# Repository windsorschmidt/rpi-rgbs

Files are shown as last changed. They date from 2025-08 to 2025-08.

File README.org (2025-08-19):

#+OPTIONS: toc:nil

* About

TV-compatible RGBS video output board for Raspberry Pi.

[[rpi-rgbs.png?raw=true]]

* Features

- 6-bit R-2R video DAC with buffered 75Ω output on VGA (DE-15) connector
- Composite video sync generator using XNOR logic gates
- Low-pass reconstruction filter audio DAC output on 3.5" phono jack

* Status

Revision 3 tested working with a Raspberry Pi 4.

* License

Circuit schematic and PCB layout are licensed under CERN-OHL-S v2.

See [[LICENSE.txt]].

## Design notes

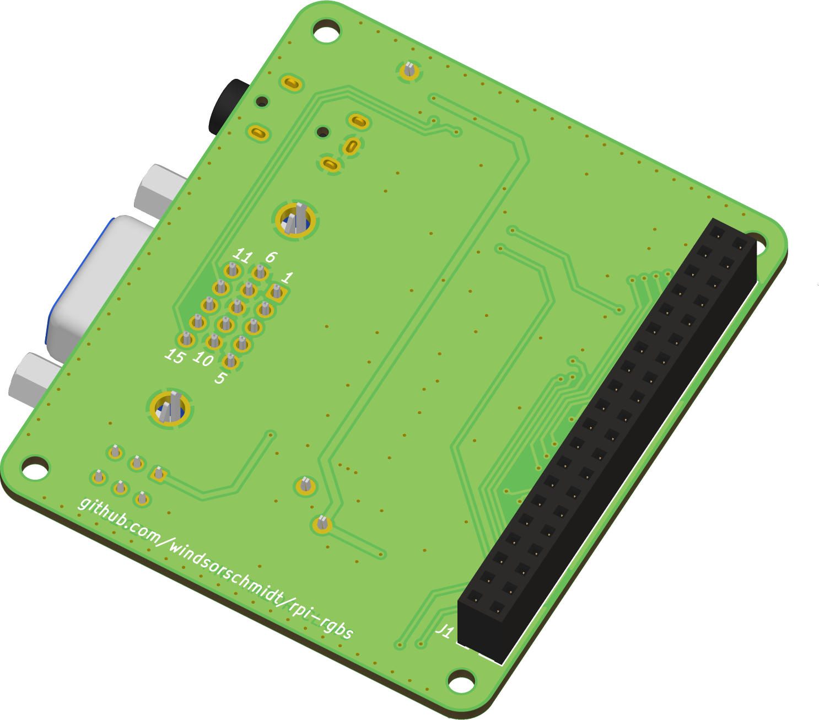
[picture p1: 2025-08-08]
render_bottom.png

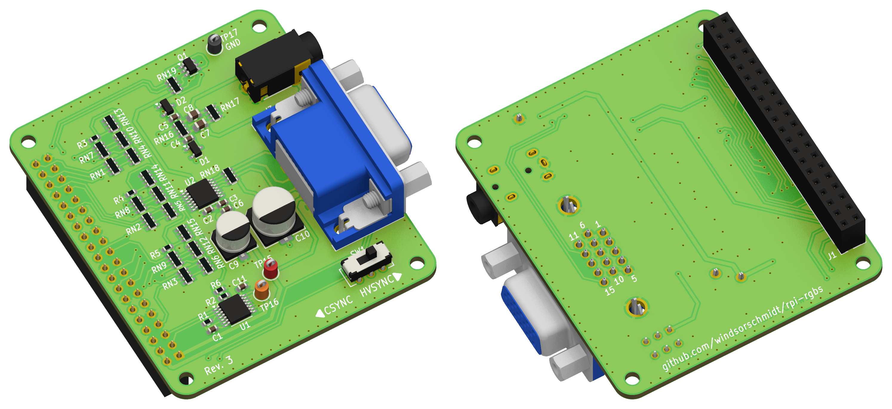
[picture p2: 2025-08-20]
rpi-rgbs.png

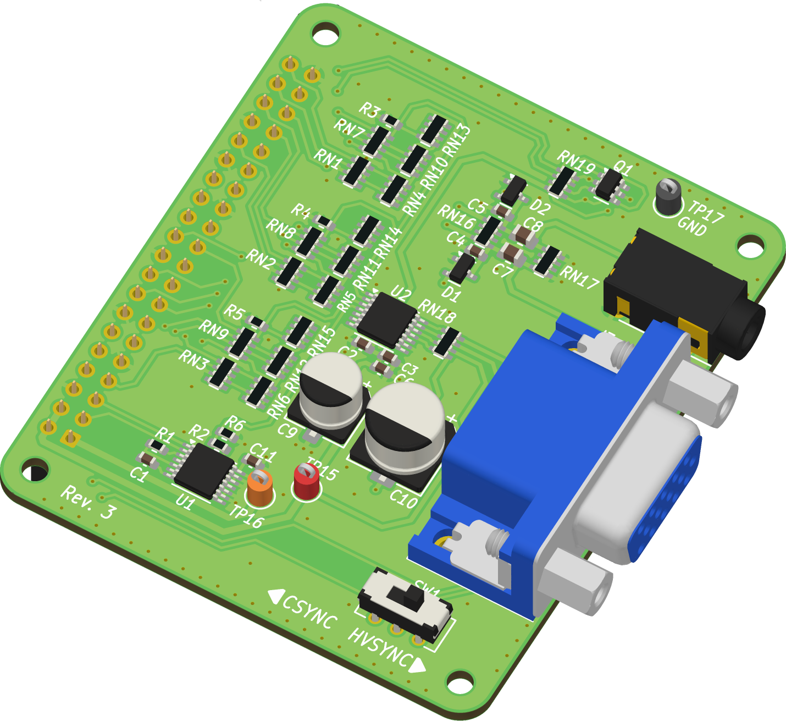
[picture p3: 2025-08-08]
render_top.png

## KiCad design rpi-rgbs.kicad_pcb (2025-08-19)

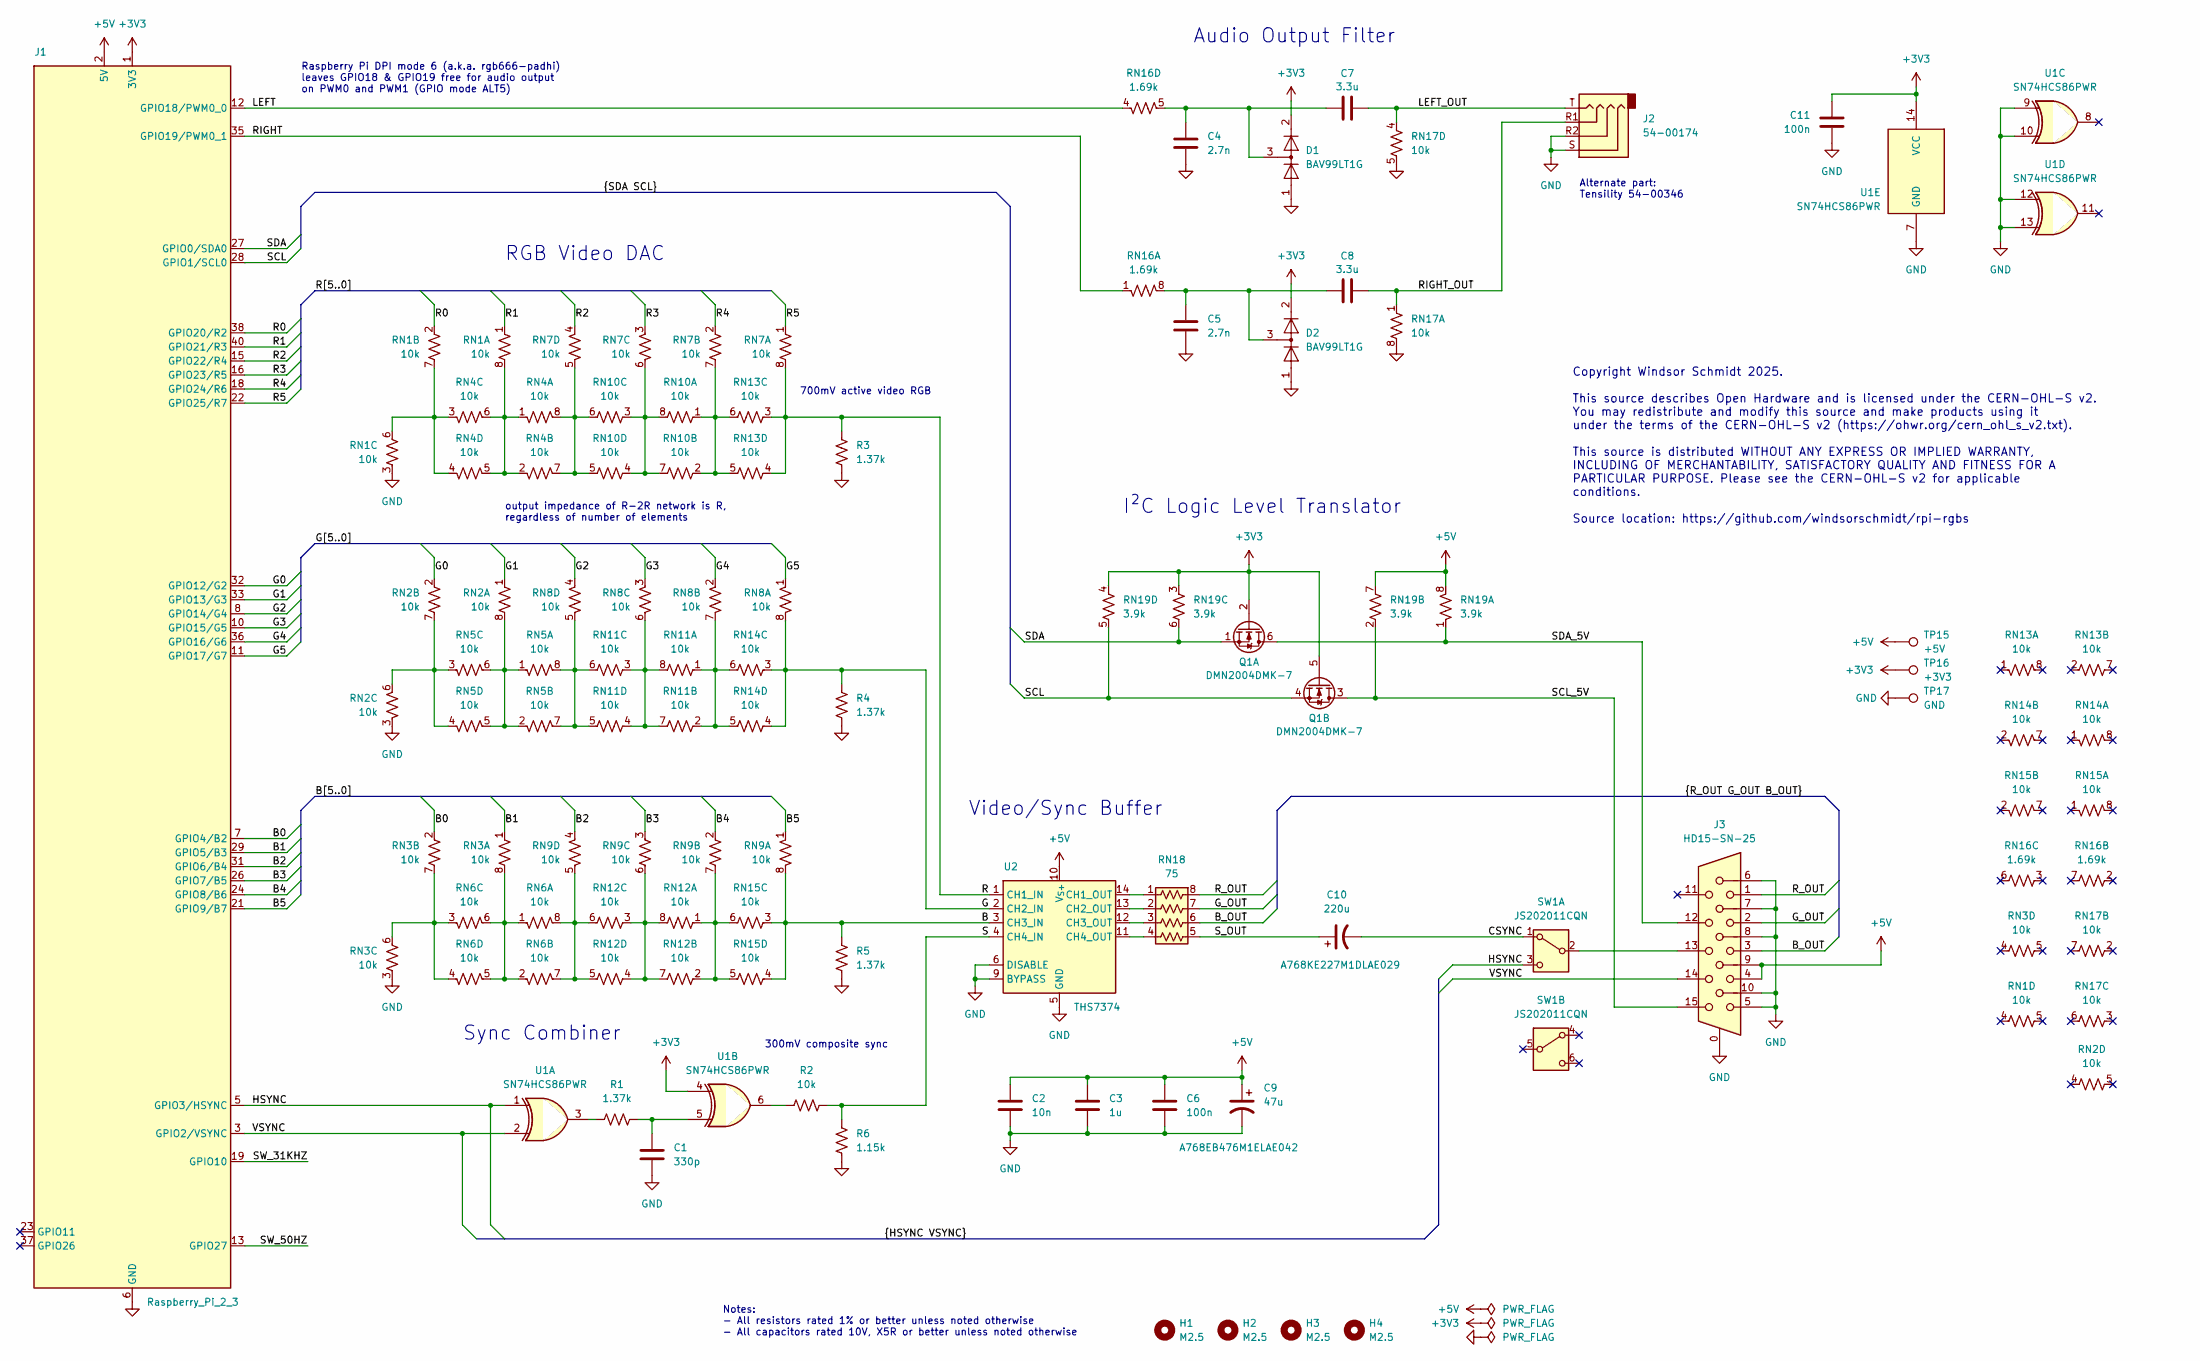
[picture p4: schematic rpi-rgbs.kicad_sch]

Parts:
C1: 330p; C_0603_1608Metric
C2: 10n; C_0603_1608Metric
C3: 1u; C_0603_1608Metric
C4, C5: 2.7n; C_0603_1608Metric
C6, C11: 100n; C_0603_1608Metric
C7, C8: 3.3u; C_0805_2012Metric
C9: 47u; CP_Elec_6.3x5.9
C10: 220u; CP_Elec_8x6.2
D1, D2: BAV99LT1G; SOT-23
H1, H2, H3, H4: M2.5; MountingHole_2.7mm_M2.5
J1: Raspberry_Pi_2_3; PinSocket_2x20_P2.54mm_Vertical
J2: 54-00174; Jack_3.5mm_Tensility_54-00174
J3: HD15-SN-25; Connector_Amphenol_L77HDE15SD1CH4FVGA
Q1: DMN2004DMK-7; SOT-23-6
R1, R3, R4, R5: 1.37k; R_0603_1608Metric
R2: 10k; R_0603_1608Metric
R6: 1.15k; R_0603_1608Metric
RN1, RN2, RN3, RN4, RN5, RN6, RN7, RN8, RN9, RN10, RN11, RN12, RN13, RN14, RN15, RN17: 10k; R_Array_Convex_4x0603
RN16: 1.69k; R_Array_Convex_4x0603
RN18: 75; R_Array_Convex_4x0603
RN19: 3.9k; R_Array_Convex_4x0603
SW1: JS202011CQN; SW_CK_JS202011CQN_DPDT_Straight
TP15: +5V; TestPoint_Loop_D1.80mm_Drill1.0mm_Beaded
TP16: +3V3; TestPoint_Loop_D1.80mm_Drill1.0mm_Beaded
TP17: GND; TestPoint_Loop_D1.80mm_Drill1.0mm_Beaded
U1: SN74HCS86PWR; TSSOP-14_4.4x5mm_P0.65mm
U2: THS7374; TSSOP-14_4.4x5mm_P0.65mm

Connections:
+3V3: C11.1, D1.2 (A), D2.2 (A), J1.1 (3V3), Q1.2 (G), Q1.5 (G), RN19.3 (R3.1), RN19.4 (R4.1), TP16.1, U1.4, U1.14 (VCC)
+5V: C2.1, C3.2, C6.1, C9.1, J1.2 (5V), J1.4 (5V), J3.4, J3.9, RN19.7 (R2.2), RN19.8 (R1.2), TP15.1, U2.10 (V_{S+})
/B: R5.1, RN9.8 (R1.2), RN15.3 (R3.1), RN15.4 (R4.1), U2.3 (CH3_IN)
/B0: J1.7 (GPIO4/B2), RN3.2 (R2.1)
/B1: J1.29 (GPIO5/B3), RN3.1 (R1.1)
/B2: J1.31 (GPIO6/B4), RN9.4 (R4.1)
/B3: J1.26 (GPIO7/B5), RN9.3 (R3.1)
/B4: J1.24 (GPIO8/B6), RN9.2 (R2.1)
/B5: J1.21 (GPIO9/B7), RN9.1 (R1.1)
/B_OUT: J3.3, RN18.6
/CSYNC: C10.2, SW1.1 (A)
/G: R4.1, RN8.8 (R1.2), RN14.3 (R3.1), RN14.4 (R4.1), U2.2 (CH2_IN)
/G0: J1.32 (GPIO12/G2), RN2.2 (R2.1)
/G1: J1.33 (GPIO13/G3), RN2.1 (R1.1)
/G2: J1.8 (GPIO14/G4), RN8.4 (R4.1)
/G3: J1.10 (GPIO15/G5), RN8.3 (R3.1)
/G4: J1.36 (GPIO16/G6), RN8.2 (R2.1)
/G5: J1.11 (GPIO17/G7), RN8.1 (R1.1)
/G_OUT: J3.2, RN18.7
/HSYNC: J1.5 (GPIO3/HSYNC), SW1.3 (C), U1.1
/LEFT: J1.12 (GPIO18/PWM0_0), RN16.4 (R4.1)
/LEFT_OUT: C7.2, J2.T, RN17.4 (R4.1)
/R: R3.1, RN7.8 (R1.2), RN13.3 (R3.1), RN13.4 (R4.1), U2.1 (CH1_IN)
/R0: J1.38 (GPIO20/R2), RN1.2 (R2.1)
/R1: J1.40 (GPIO21/R3), RN1.1 (R1.1)
/R2: J1.15 (GPIO22/R4), RN7.4 (R4.1)
/R3: J1.16 (GPIO23/R5), RN7.3 (R3.1)
/R4: J1.18 (GPIO24/R6), RN7.2 (R2.1)
/R5: J1.22 (GPIO25/R7), RN7.1 (R1.1)
/RIGHT: J1.35 (GPIO19/PWM0_1), RN16.1 (R1.1)
/RIGHT_OUT: C8.2, J2.R1, RN17.1 (R1.1)
/R_OUT: J3.1, RN18.8
/S: R2.2, R6.1, U2.4 (CH4_IN)
/SCL: J1.28 (GPIO1/SCL0), Q1.4 (S), RN19.5 (R4.2)
/SCL_5V: J3.15, Q1.3 (D), RN19.2 (R2.1)
/SDA: J1.27 (GPIO0/SDA0), Q1.1 (S), RN19.6 (R3.2)
/SDA_5V: J3.12, Q1.6 (D), RN19.1 (R1.1)
/SW_31KHZ: J1.19 (GPIO10)
/SW_50HZ: J1.13 (GPIO27)
/S_OUT: C10.1, RN18.5
/VSYNC: J1.3 (GPIO2/VSYNC), J3.14, U1.2
GND: C1.2, C2.2, C3.1, C4.2, C5.2, C6.2, C9.2, C11.2, D1.1 (K), D2.1 (K), J1.6 (GND), J1.9 (GND), J1.14 (GND), J1.20 (GND), J1.25 (GND), J1.30 (GND), J1.34 (GND), J1.39 (GND), J2.R2, J2.S, J3.0, J3.5, J3.6, J3.7, J3.8, J3.10, R3.2, R4.2, R5.2, R6.2, RN1.3 (R3.1), RN2.3 (R3.1), RN3.3 (R3.1), RN17.5 (R4.2), RN17.8 (R1.2), TP17.1, U1.7 (GND), U1.9, U1.10, U1.12, U1.13, U2.5 (GND), U2.6 (DISABLE), U2.9 (BYPASS)
unnamed: C1.1, R1.2, U1.5
unnamed: R1.1, U1.3
unnamed: R2.1, U1.6
unnamed: RN1.8 (R1.2), RN4.1 (R1.1), RN4.2 (R2.1), RN4.5 (R4.2), RN4.6 (R3.2)
unnamed: RN1.6 (R3.2), RN1.7 (R2.2), RN4.3 (R3.1), RN4.4 (R4.1)
unnamed: RN2.8 (R1.2), RN5.1 (R1.1), RN5.2 (R2.1), RN5.5 (R4.2), RN5.6 (R3.2)
unnamed: RN2.6 (R3.2), RN2.7 (R2.2), RN5.3 (R3.1), RN5.4 (R4.1)
unnamed: RN3.8 (R1.2), RN6.1 (R1.1), RN6.2 (R2.1), RN6.5 (R4.2), RN6.6 (R3.2)
unnamed: RN3.6 (R3.2), RN3.7 (R2.2), RN6.3 (R3.1), RN6.4 (R4.1)
unnamed: RN7.7 (R2.2), RN10.1 (R1.1), RN10.2 (R2.1), RN13.5 (R4.2), RN13.6 (R3.2)
unnamed: RN7.6 (R3.2), RN10.3 (R3.1), RN10.4 (R4.1), RN10.7 (R2.2), RN10.8 (R1.2)
unnamed: RN4.7 (R2.2), RN4.8 (R1.2), RN7.5 (R4.2), RN10.5 (R4.2), RN10.6 (R3.2)
unnamed: RN8.7 (R2.2), RN11.1 (R1.1), RN11.2 (R2.1), RN14.5 (R4.2), RN14.6 (R3.2)
unnamed: RN8.6 (R3.2), RN11.3 (R3.1), RN11.4 (R4.1), RN11.7 (R2.2), RN11.8 (R1.2)
unnamed: RN5.7 (R2.2), RN5.8 (R1.2), RN8.5 (R4.2), RN11.5 (R4.2), RN11.6 (R3.2)
unnamed: RN9.7 (R2.2), RN12.1 (R1.1), RN12.2 (R2.1), RN15.5 (R4.2), RN15.6 (R3.2)
unnamed: RN9.6 (R3.2), RN12.3 (R3.1), RN12.4 (R4.1), RN12.7 (R2.2), RN12.8 (R1.2)
unnamed: RN6.7 (R2.2), RN6.8 (R1.2), RN9.5 (R4.2), RN12.5 (R4.2), RN12.6 (R3.2)
unnamed: C5.1, C8.1, D2.3 (K), RN16.8 (R1.2)
unnamed: C4.1, C7.1, D1.3 (K), RN16.5 (R4.2)
unnamed: J3.13, SW1.2 (B)
unnamed: RN18.1, U2.14 (CH1_OUT)
unnamed: RN18.2, U2.13 (CH2_OUT)
unnamed: RN18.3, U2.12 (CH3_OUT)
unnamed: RN18.4, U2.11 (CH4_OUT)

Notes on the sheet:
Notes: - All resistors rated 1% or better unless noted otherwise - All capacitors rated 10V, X5R or better unless noted otherwise
Alternate part: Tensility 54-00346
Raspberry Pi DPI mode 6 (a.k.a. rgb666-padhi) leaves GPIO18 & GPIO19 free for audio output on PWM0 and PWM1 (GPIO mode ALT5)
700mV active video RGB
Audio Output Filter
Sync Combiner
300mV composite sync
I²C Logic Level Translator
RGB Video DAC
Copyright Windsor Schmidt 2025. This source describes Open Hardware and is licensed under the CERN-OHL-S v2. You may redistribute and modify this source and make products using it under the terms of the CERN-OHL-S v2 (https://ohwr.org/cern_ohl_s_v2.txt). This source is distributed WITHOUT ANY EXPRE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
output impedance of R-2R network is R, regardless of number of elements
Video/Sync Buffer

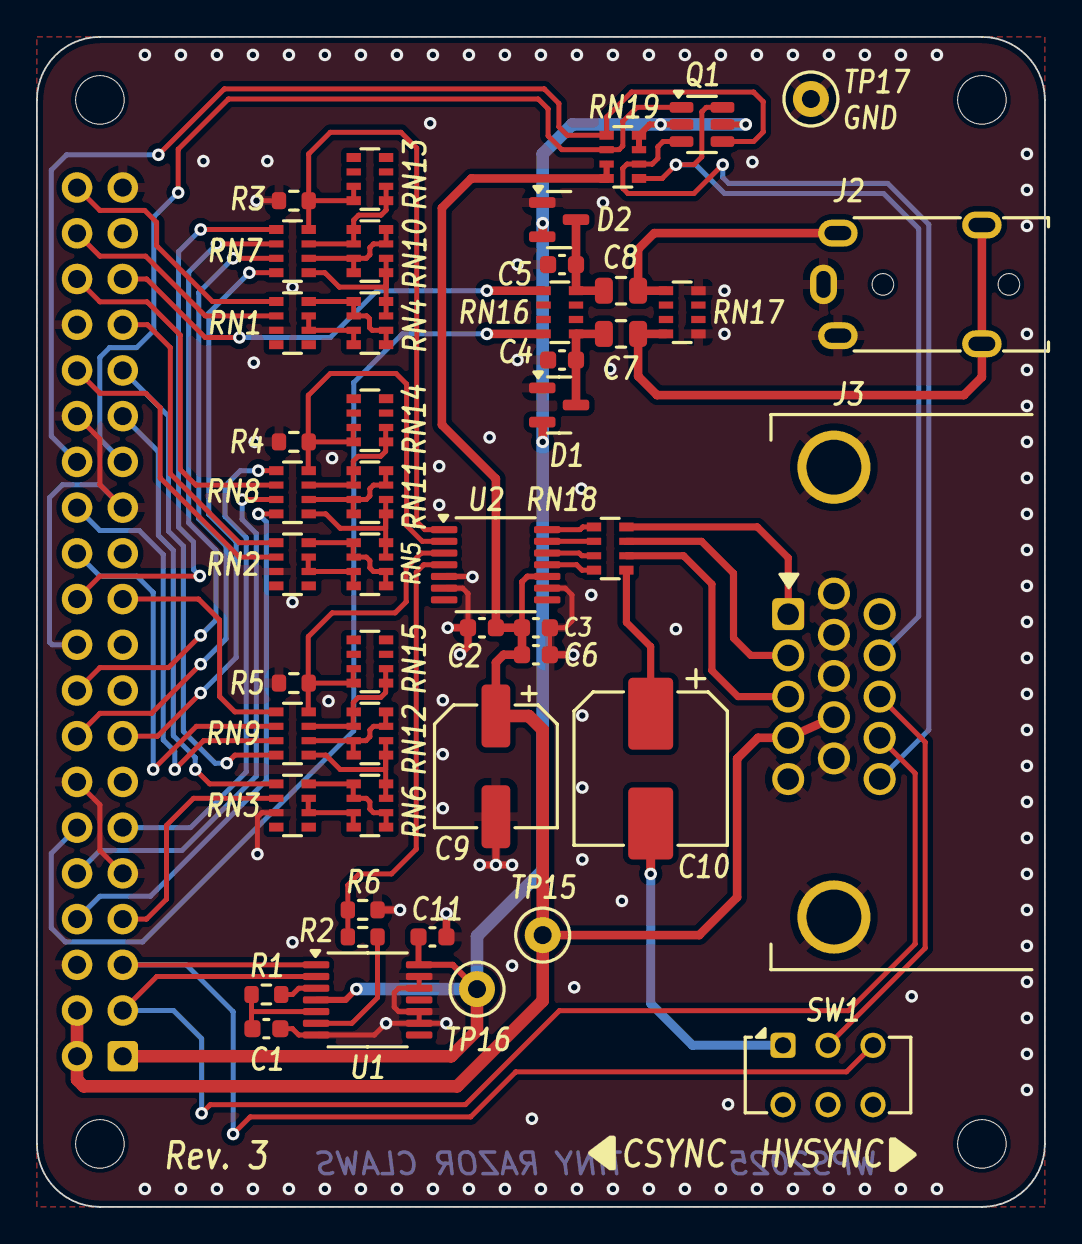
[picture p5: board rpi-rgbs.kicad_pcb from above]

Board: 2 copper layers, 56.0 x 65.0 mm, 52 parts (1 on the bottom side), 65 nets.

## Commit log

2025-08-19 tweak silkscreen
    [rpi-rgbs.kicad_pcb]
2025-08-20 update pcb image
